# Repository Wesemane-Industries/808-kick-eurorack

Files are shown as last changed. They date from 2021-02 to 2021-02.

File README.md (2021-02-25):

# 808-kick-eurorack
808 kick (bass drum) for eurorack / modular synth

## 3D view
### 3D view front
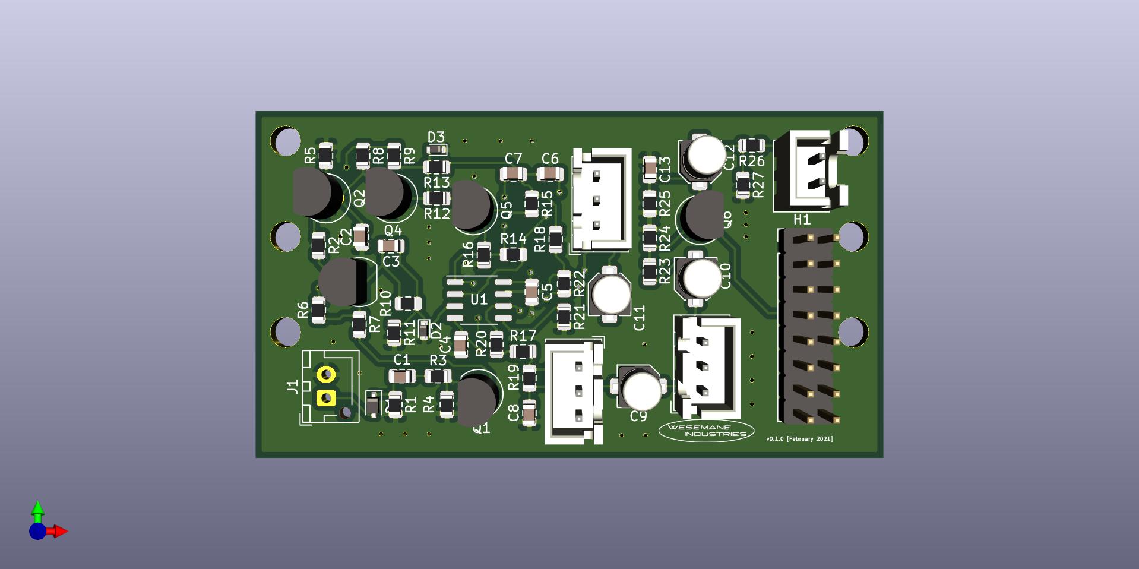
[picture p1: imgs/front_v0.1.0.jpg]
3D view front


### 3D view back
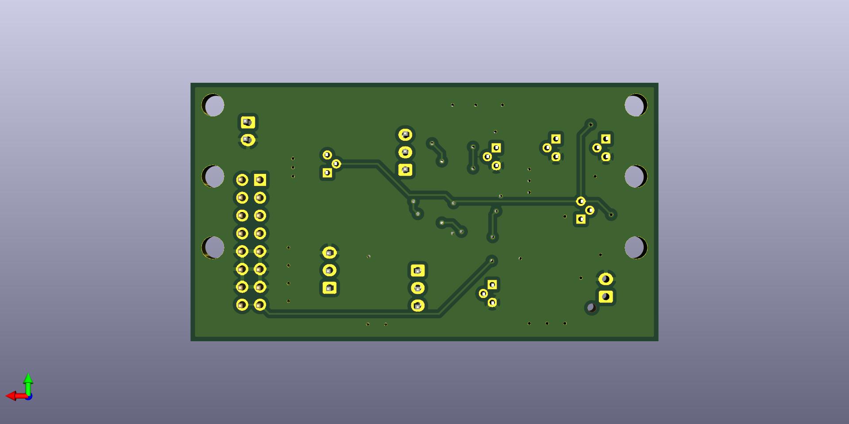
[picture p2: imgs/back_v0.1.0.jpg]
3D view back


## ToDo
* add front panel for potentiometers 
* add JST connectors to BOM
* add Mouser shopping cart to get all parts

## Release Notes
* **v0.1.0**
    * first version of schematic and layout done and ordered

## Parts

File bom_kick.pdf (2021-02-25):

bom_kick

Id Designator | Package | Q | Designation
1 R6,R11 | R_0805_2012Metric | | 2 4.7k
2 C1,C2,C4,C5,C8 | C_0805_2012Metric | | 5 100n
3 C3,C6,C7 | C_0805_2012Metric | | 3 15n
4 C9,C10,C12 | C_Elec_4x5.4 | | 3 0.47/50
5 C11 | C_Elec_4x5.4 | | 1 33/6.3
6 C13 | C_0805_2012Metric | | 1 220p
7 D1 | D_SOD-323F | | 1 1N914A
8 D2,D3 | D_SOD-523 | | 2 1N4148
9 H1 | PinHeader_2x08_P2.54mm_Vertical | | 1 PIN_HEADER_2x8
10 J1 | JST_XH_B2B-XH-AM_1x02_P2.50mm_V 1 CV IN
11 J3 | JST_XH_B2B-XH-A_1x02_P2.50mm_Ve 1 TRIGGER OUT
12 Q1,Q2,Q4,Q5,Q6 | TO-92 | | 5 BC546
13 Q3 | TO-92 | | 1 BC556
14 R1,R10,R12,R24,R27 R_0805_2012Metric | 5 100k
15 R2 | R_0805_2012Metric | | 1 8.2k
16 R3,R9,R21 | R_0805_2012Metric | | 3 22k
17 R4,R7,R19 | R_0805_2012Metric | | 3 10k
18 R5 | R_0805_2012Metric | | 1 2.7k
19 R8,R13,R14 | R_0805_2012Metric | | 3 1M
20 R15,R25 | R_0805_2012Metric | | 2 6.8k
21 R16,R20,R22 | R_0805_2012Metric | | 3 47k
22 R17 | R_0805_2012Metric | | 1 220
23 R18 | R_0805_2012Metric | | 1 470k
24 R23 | R_0805_2012Metric | | 1 82k
25 R26 | R_0805_2012Metric | | 1 1k
26 RV1,RV2 | JST_XH_B3B-XH-A_1x03_P2.50mm_Ve 2 10k
27 RV3 | JST_XH_B3B-XH-A_1x03_P2.50mm_Ve 1 500kB
28 U1 | SO-8_3.9x4.9mm_P1.27mm | | 1 TL072P

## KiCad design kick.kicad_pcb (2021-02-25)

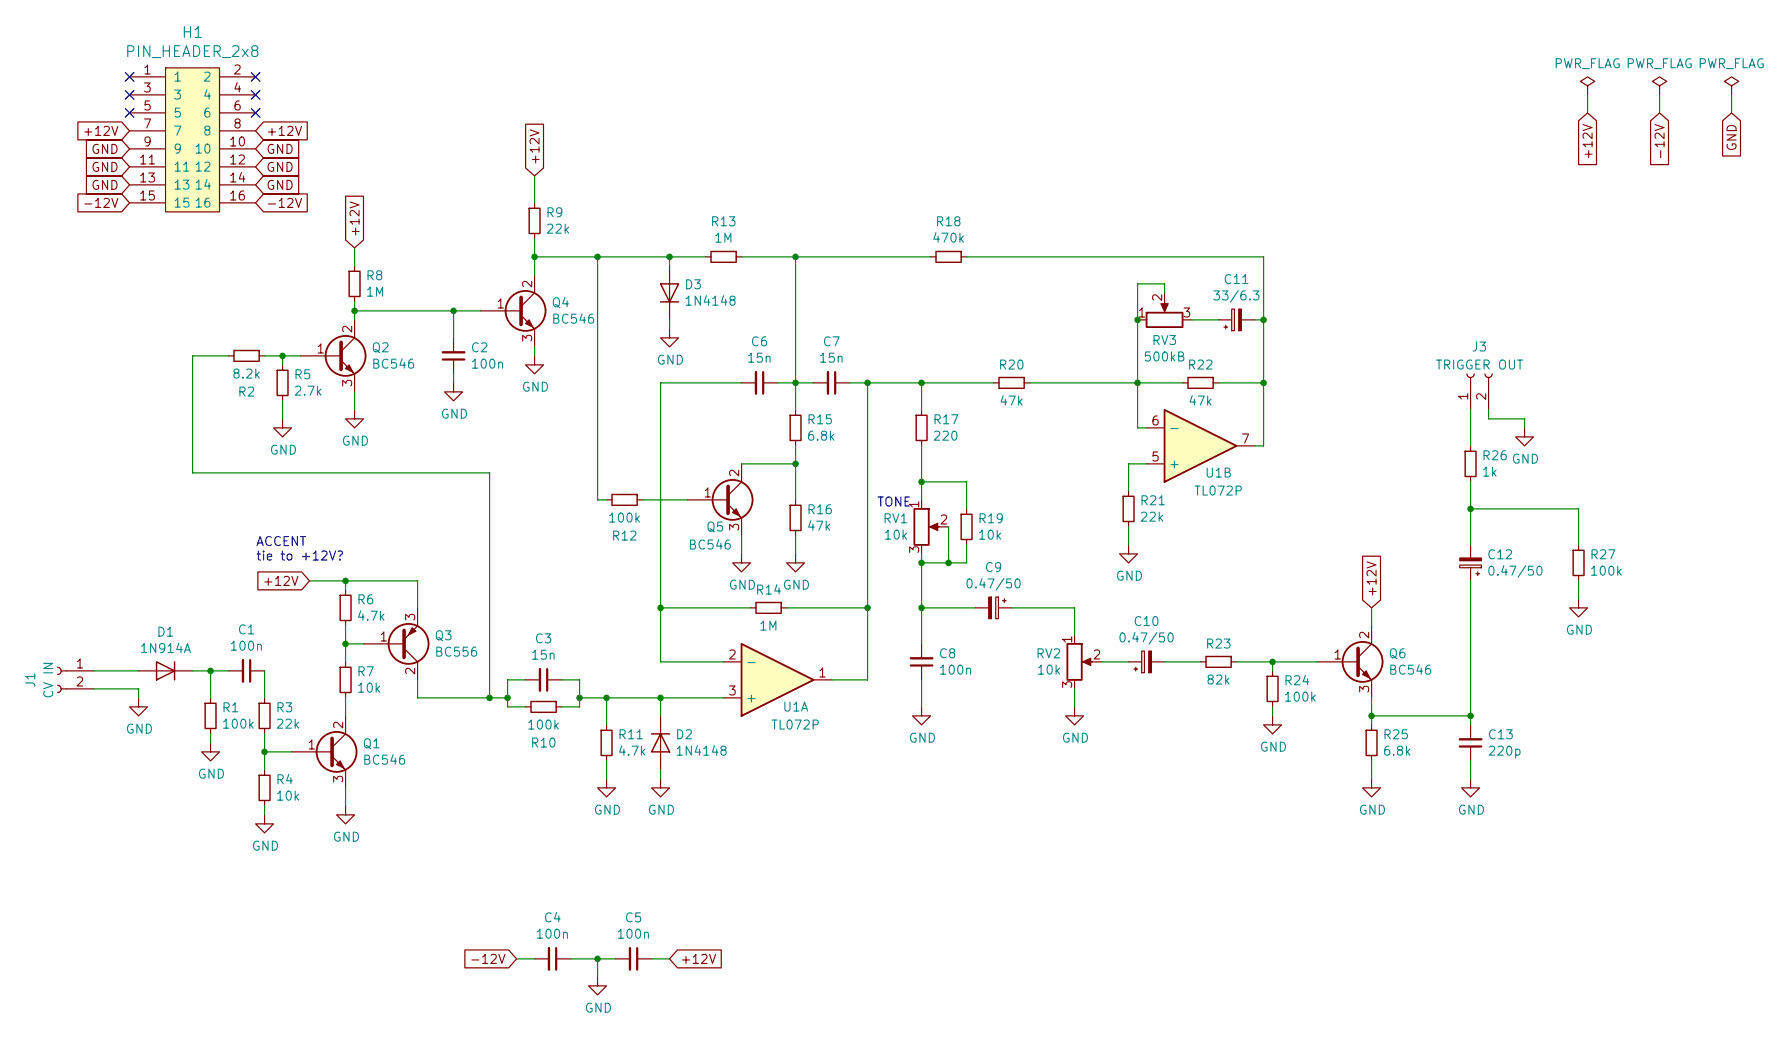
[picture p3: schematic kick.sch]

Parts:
C1, C2, C4, C5, C8: 100n; C_0805_2012Metric
C3, C6, C7: 15n; C_0805_2012Metric
C9, C10, C12: 0.47/50; C_Elec_4x5.4
C11: 33/6.3; C_Elec_4x5.4
C13: 220p; C_0805_2012Metric
D1: 1N914A; D_SOD-323F
D2, D3: 1N4148; D_SOD-523
H1: PIN_HEADER_2x8; PinHeader_2x08_P2.54mm_Vertical
J1: CV IN; JST_XH_B2B-XH-AM_1x02_P2.50mm_Vertical
J3: TRIGGER OUT; JST_XH_B2B-XH-A_1x02_P2.50mm_Vertical
Q1, Q2, Q4, Q5, Q6: BC546; TO-92
Q3: BC556; TO-92
R1, R10, R12, R24, R27: 100k; R_0805_2012Metric
R2: 8.2k; R_0805_2012Metric
R3, R9, R21: 22k; R_0805_2012Metric
R4, R7, R19: 10k; R_0805_2012Metric
R5: 2.7k; R_0805_2012Metric
R6, R11: 4.7k; R_0805_2012Metric
R8, R13, R14: 1M; R_0805_2012Metric
R15, R25: 6.8k; R_0805_2012Metric
R16, R20, R22: 47k; R_0805_2012Metric
R17: 220; R_0805_2012Metric
R18: 470k; R_0805_2012Metric
R23: 82k; R_0805_2012Metric
R26: 1k; R_0805_2012Metric
RV1, RV2: 10k; JST_XH_B3B-XH-A_1x03_P2.50mm_Vertical
RV3: 500kB; JST_XH_B3B-XH-A_1x03_P2.50mm_Vertical
U1: TL072P; SO-8_3.9x4.9mm_P1.27mm

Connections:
+12V: C5.1, H1.7, H1.8, Q3.3 (E), Q6.2 (C), R6.1, R8.1, R9.1, U1.8 (V+)
-12V: C4.2, H1.15, H1.16, U1.4 (V-)
GND: C2.1, C4.1, C5.2, C8.1, C13.1, D2.2 (A), D3.1 (K), H1.9, H1.10, H1.11, H1.12, H1.13, H1.14, J1.2, J3.2, Q1.3 (E), Q2.3 (E), Q4.3 (E), Q5.3 (E), R1.2, R4.2, R5.2, R11.2, R16.2, R21.2, R24.2, R25.2, R27.2, RV2.3
unnamed: C1.1, R3.1
unnamed: C1.2, D1.1 (K), R1.1
unnamed: C2.2, Q2.2 (C), Q4.1 (B), R8.2
unnamed: C3.1, D2.1 (K), R10.1, R11.1, U1.3 (+)
unnamed: C3.2, Q3.2 (C), R2.2, R10.2
unnamed: C6.1, C7.2, R13.1, R15.1, R18.2
unnamed: C6.2, R14.2, U1.2 (-)
unnamed: C7.1, R14.1, R17.1, R20.2, U1.1
unnamed: C8.2, C9.2, R19.2, RV1.2, RV1.3
unnamed: C9.1, RV2.1
unnamed: C10.1, RV2.2
unnamed: C10.2, R23.2
unnamed: C11.1, RV3.3
unnamed: C11.2, R18.1, R22.1, U1.7
unnamed: C12.1, C13.2, Q6.3 (E), R25.1
unnamed: C12.2, R26.2, R27.1
unnamed: D1.2 (A), J1.1
unnamed: D3.2 (A), Q4.2 (C), R9.2, R12.2, R13.2
unnamed: J3.1, R26.1
unnamed: Q1.1 (B), R3.2, R4.1
unnamed: Q1.2 (C), R7.2
unnamed: Q2.1 (B), R2.1, R5.1
unnamed: Q3.1 (B), R6.2, R7.1
unnamed: Q5.1 (B), R12.1
unnamed: Q5.2 (C), R15.2, R16.1
unnamed: Q6.1 (B), R23.1, R24.1
unnamed: R17.2, R19.1, RV1.1
unnamed: R20.1, R22.2, RV3.1, RV3.2, U1.6 (-)
unnamed: R21.1, U1.5 (+)

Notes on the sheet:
TONE
ACCENT tie to +12V?

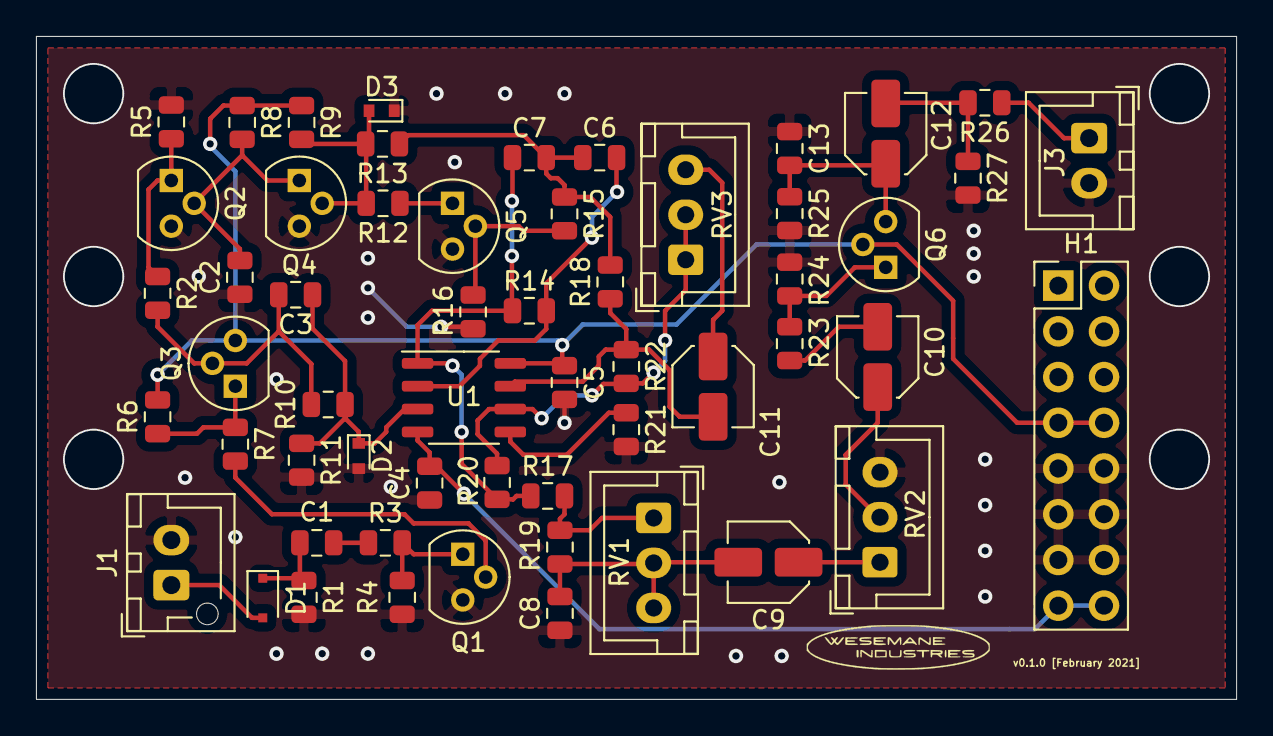
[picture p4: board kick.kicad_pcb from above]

Board: 2 copper layers, 66.7 x 36.8 mm, 56 parts (0 on the bottom side), 32 nets.
